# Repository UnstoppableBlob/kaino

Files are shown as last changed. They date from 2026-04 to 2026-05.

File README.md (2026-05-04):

# Kaino (or Kiano)

## What this project is

Here's a short story about this project! I wanted a keyboard from Casio, but it was too expensive for me, so I made my own. I just made a keyboard which should theoretically be able to connect to my computer, and use LMMS that's on my computer, to play sounds that sound exactly like a real piano! 

## How I made it

I made the schematic and PCB in Kicad, which is my prefered software for this type of stuff. I used Shapr3D on my Ipad for the model of the case. I also used Shapr3D's "Visualize" feature for the renders that I got. I plan to use Cherry MX mechanical keyswitches, which are what I have on my pcb renders. I have made my own custom keycap in Shapr3D, which is what I plan to print out and use. Not only does it look like a piano, it feels like one, too. I have put a hole in all of the piano keycaps, and made them a hinge. Whenever you press on a key, it will have the same rotational movement as a really key has. Obviously, I'm limited with the materials of the keycaps that I produce, as I don't have access to the premium ceramic keys that the real pianos have. In addition, even if I did have access to them, the mechanical keyswitches that I'm using wouldn't be able to support the weight of them, at least without substantial springing. My banner image for it is AI Generated, just a disclaimer, hope that it doesn't cause any issues.

## Schematic

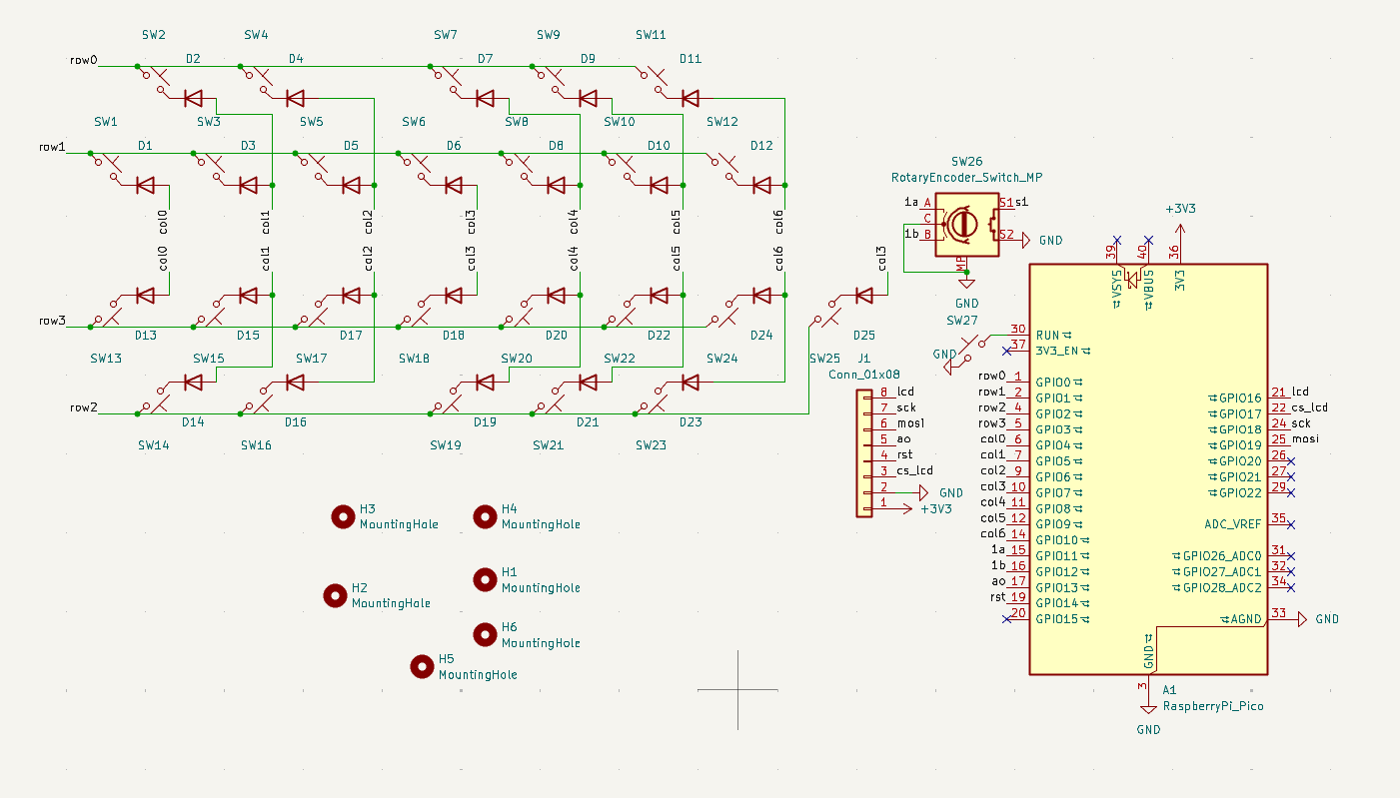
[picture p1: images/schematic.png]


## PCB

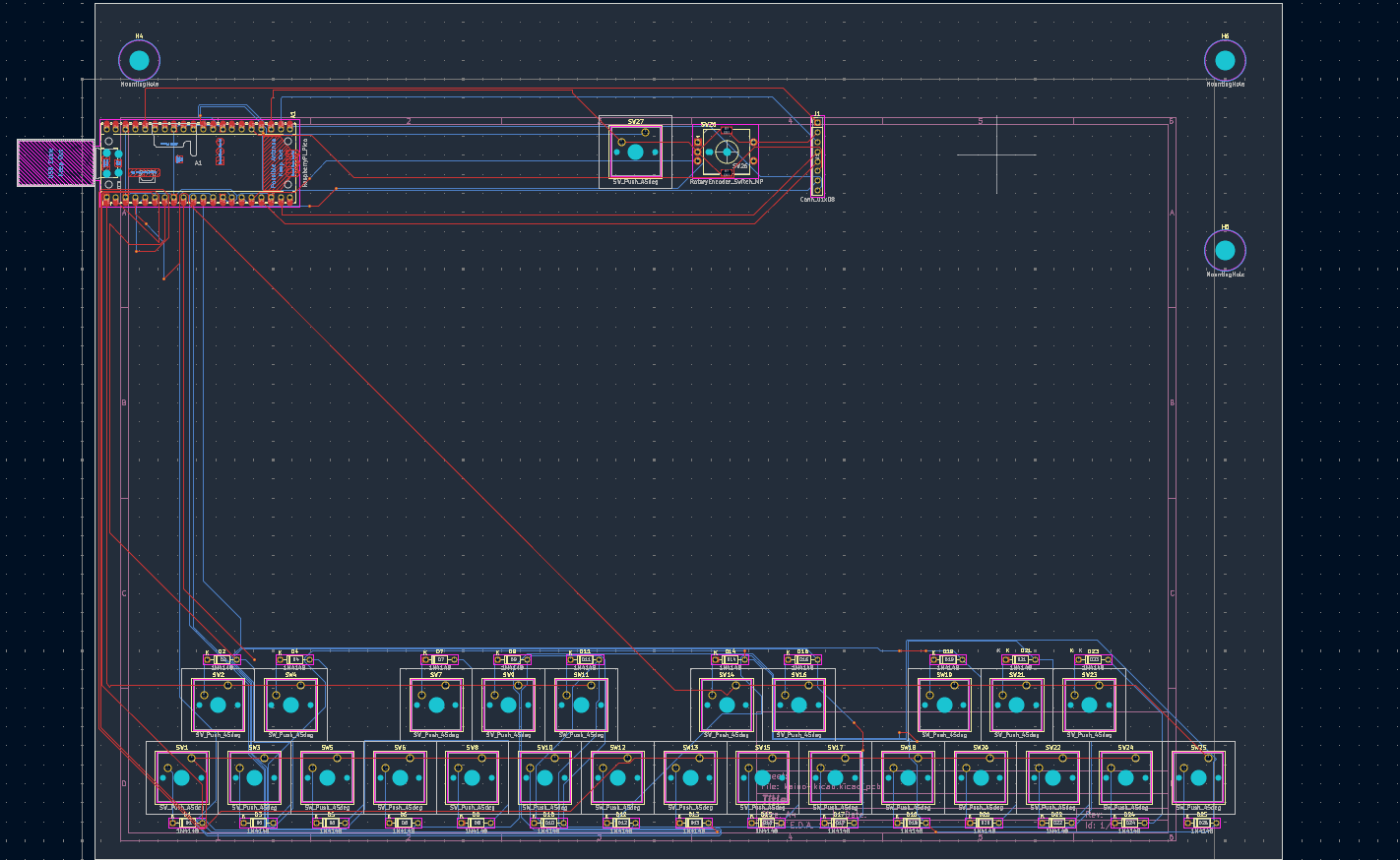
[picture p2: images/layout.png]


## Render #1

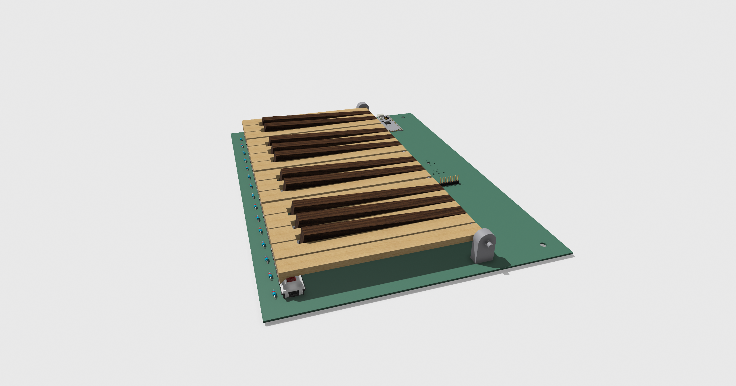
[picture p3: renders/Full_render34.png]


## Render #2

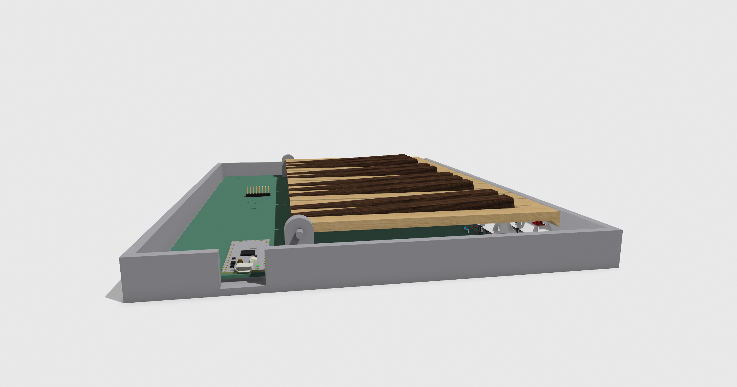
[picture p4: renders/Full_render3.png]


## Render #3

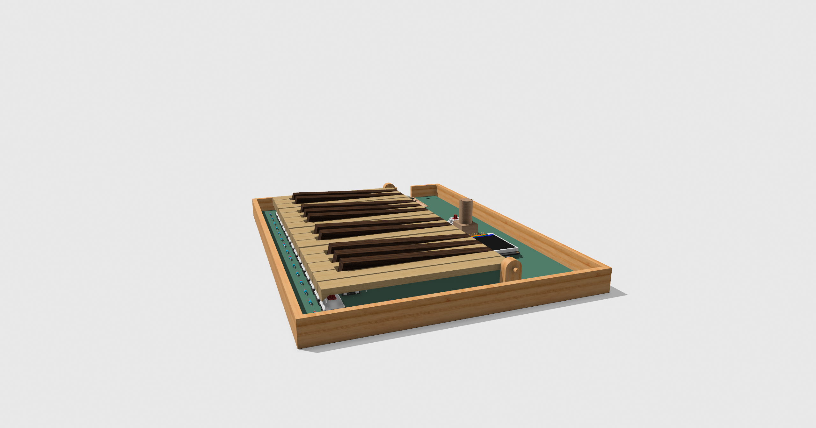
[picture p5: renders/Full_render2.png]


## Render #4

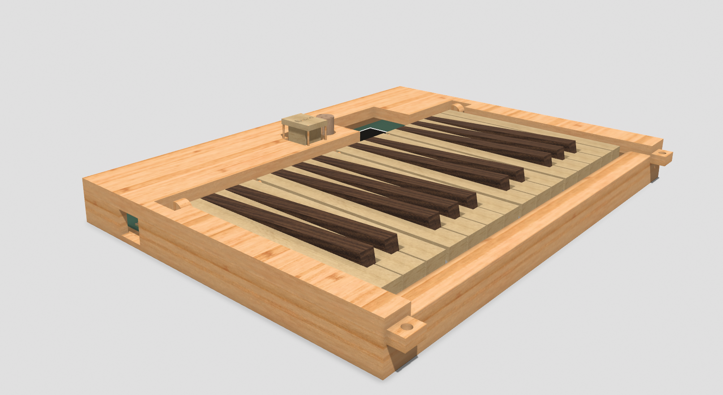
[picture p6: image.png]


## BOM
| Item | Description | Quantity | Unit Price | Total Price | Total (with tax & shipping incl.) | Running Total | Link | | | | | |
|---|---|---|---|---|---|---|---|---|---|---|---|---|
| PCB | PCB from jlcpcb | 5 (jlcpcb minimum) | $0.00 | $0.00 | $0.00 | $0.00 | https://cart.jlcpcb.com/quote | | | | | |
| Cherry MX switches | Cherry MX Switches | 1 | $0.00 | $0.00 | $0.00 | $0.00 | https://www.amazon.com/OUTEMU-Red-Switches-Pin-Switch/dp/B095W1QYPJ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 | | | | | |
| Raspberry Pi pico | MCU | NA | $0.00 | $0.00 | $0.00 | $0.00 | https://www.amazon.com/gp/product/B0C6Q67V97?smid=A1YZW40LYQY3L1&psc=1 | | | | | Since I already have plenty of these in my house, I decided to put $0, but included a link |
| 1N4148W (100pcs) | Diodes | 1 | $0.00 | $0.00 | $0 | $0.00 | https://www.aliexpress.us/item/3256807716771073.html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 | | | | | |
| 3D Prints | 3D printed keys and case | NA | $0 | $0 | My own printer | $0 | NA | | | | | |
| Rotary Encoder (5pcs) | EC11 rotary encoder | 1 | $0.00 | $0.00 | $0 | $0.00 | https://www.amazon.com/gp/product/B0C6Q67V97?smid=A1YZW40LYQY3L1&psc=1 | | | | | I already have some of these lying around from hackpad a long time ago |
| Adafruit 1.8 TFT | LCD Display | 1 | $0.00 | $0.00 | $0.00 | $0.00 | https://www.adafruit.com/product/358 | | | | | |
| | | | | | | Running total is 0 because I'm paying for all costs related to buying parts | | | | | | |

The total amount of money that I would have to spend would be $72.18, since I'm buying parts myself

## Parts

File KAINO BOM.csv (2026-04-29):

Item | Description | Quantity | Unit Price | Total Price | Total (with tax & shipping incl.) | Running Total | Link
PCB | PCB from jlcpcb | 5 (jlcpcb minimum) | $15.43 | $15.43 | $29.84 | $0.00 | https://cart.jlcpcb.com/quote
Kailh Choc v1 (70pcs) | Cherry MX Switches | 1 | $10.99 | $10.99 | $12.36 | $0.00 | https://www.amazon.com/OUTEMU-Red-Switches-Pin-Switch/dp/B095W1QYPJ?sbo=RZvfv%2F%2FHxDF%2BO5021pAnSA%3D%3D
Raspberry Pi pico | MCU | NA | $0.00 | $0.00 | $0.00 | $0.00 | https://www.amazon.com/gp/product/B0C6Q67V97?smid=A1YZW40LYQY3L1&psc=1 | Since I already have plenty of these in my house, I decided to put $0, but included a link
1N4148W (100pcs) | Diodes | 1 | $0.99 | $0.99 | $1 | $0.00 | https://www.aliexpress.us/item/3256807716771073.html?mp=1
3D Prints | 3D printed keys and case | NA | $0 | $0 | My own printer | $0 | NA
Rotary Encoder (5pcs) | EC11 rotary encoder | 1 | $0.00 | $0.00 | $0 | $0.00 | https://www.amazon.com/gp/product/B0C6Q67V97?smid=A1YZW40LYQY3L1&psc=1 | I already have some of these lying around from hackpad a long time ago
 |  |  |  |  |  | Running total is 0 because I'm paying for all costs related to buying parts

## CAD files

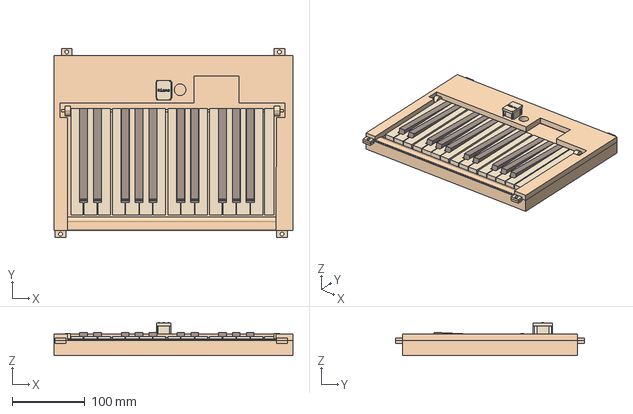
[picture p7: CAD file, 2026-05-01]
CAD/case.step
328.0 x 260.0 x 45.8 mm

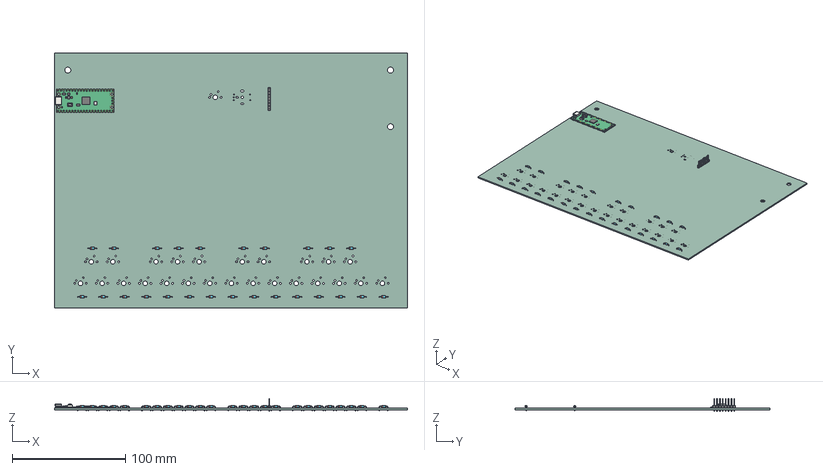
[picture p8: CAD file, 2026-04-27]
kaino-kicad/.step
311.8 x 225.0 x 11.5 mm
D_DO-35_SOD27_P7.62mm_Horizontal x 25
RaspberryPi_Pico_Module_KiCad
PinHeader_1x08_P2.54mm_Vertical
kaino-kicad_PCB

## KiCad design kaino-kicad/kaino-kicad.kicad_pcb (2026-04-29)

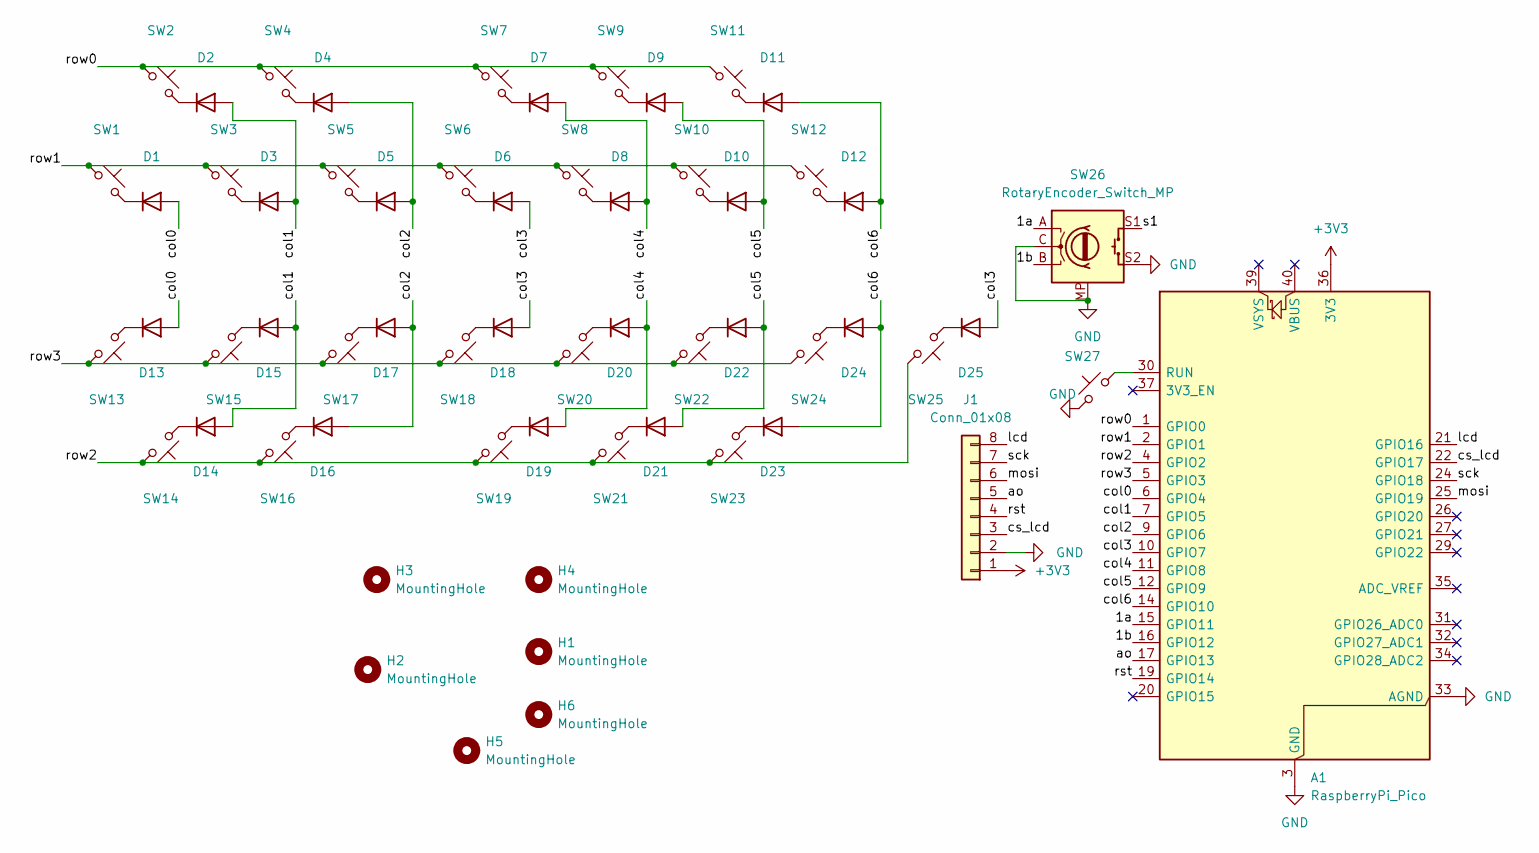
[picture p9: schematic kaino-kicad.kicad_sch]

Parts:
A1: RaspberryPi_Pico; RaspberryPi_Pico_Common_Unspecified
D1, D2, D3, D4, D5, D6, D7, D8, D9, D10, D11, D12, D13, D14, D15, D16, D17, D18, D19, D20, D21, D22, D23, D24, D25: 1N4148; D_DO-35_SOD27_P7.62mm_Horizontal
H1, H2, H3, H4, H5, H6: MountingHole; MountingHole_5.3mm_M5
J1: Conn_01x08; PinHeader_1x08_P2.54mm_Vertical
SW1, SW2, SW3, SW4, SW5, SW6, SW7, SW8, SW9, SW10, SW11, SW12, SW13, SW14, SW15, SW16, SW17, SW18, SW19, SW20, SW21, SW22, SW23, SW24, SW25, SW27: SW_Push_45deg; SW_Cherry_MX_1.00u_PCB
SW26: RotaryEncoder_Switch_MP; RotaryEncoder_Alps_EC11E-Switch_Vertical_H20mm_MountingHoles

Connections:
+3V3: A1.36 (3V3), J1.1
/1a: A1.15 (GPIO11), SW26.A
/1b: A1.16 (GPIO12), SW26.B
/ao: A1.17 (GPIO13), J1.5
/col0: A1.6 (GPIO4), D1.2 (A), D13.2 (A)
/col1: A1.7 (GPIO5), D2.2 (A), D3.2 (A), D14.2 (A), D15.2 (A)
/col2: A1.9 (GPIO6), D4.2 (A), D5.2 (A), D16.2 (A), D17.2 (A)
/col3: A1.10 (GPIO7), D6.2 (A), D18.2 (A), D25.2 (A)
/col4: A1.11 (GPIO8), D7.2 (A), D8.2 (A), D19.2 (A), D20.2 (A)
/col5: A1.12 (GPIO9), D9.2 (A), D10.2 (A), D21.2 (A), D22.2 (A)
/col6: A1.14 (GPIO10), D11.2 (A), D12.2 (A), D23.2 (A), D24.2 (A)
/cs_lcd: A1.22 (GPIO17), J1.3
/lcd: A1.21 (GPIO16), J1.8
/mosi: A1.25 (GPIO19), J1.6
/row0: A1.1 (GPIO0), SW2.1, SW4.1, SW7.1, SW9.1, SW11.1
/row1: A1.2 (GPIO1), SW1.1, SW3.1, SW5.1, SW6.1, SW8.1, SW10.1, SW12.1
/row2: A1.4 (GPIO2), SW14.1, SW16.1, SW19.1, SW21.1, SW23.1, SW25.1
/row3: A1.5 (GPIO3), SW13.1, SW15.1, SW17.1, SW18.1, SW20.1, SW22.1, SW24.1
/rst: A1.19 (GPIO14), J1.4
/s1: SW26.S1
/sck: A1.24 (GPIO18), J1.7
GND: A1.3 (GND), A1.8 (GND), A1.13 (GND), A1.18 (GND), A1.23 (GND), A1.28 (GND), A1.33 (AGND), A1.38 (GND), J1.2, SW26.C, SW26.MP, SW26.S2, SW27.2
unnamed: A1.30 (RUN), SW27.1
unnamed: D1.1 (K), SW1.2
unnamed: D2.1 (K), SW2.2
unnamed: D3.1 (K), SW3.2
unnamed: D4.1 (K), SW4.2
unnamed: D5.1 (K), SW5.2
unnamed: D6.1 (K), SW6.2
unnamed: D7.1 (K), SW7.2
unnamed: D8.1 (K), SW8.2
unnamed: D9.1 (K), SW9.2
unnamed: D10.1 (K), SW10.2
unnamed: D11.1 (K), SW11.2
unnamed: D12.1 (K), SW12.2
unnamed: D13.1 (K), SW13.2
unnamed: D14.1 (K), SW14.2
unnamed: D15.1 (K), SW15.2
unnamed: D16.1 (K), SW16.2
unnamed: D17.1 (K), SW17.2
unnamed: D18.1 (K), SW18.2
unnamed: D19.1 (K), SW19.2
unnamed: D20.1 (K), SW20.2
unnamed: D21.1 (K), SW21.2
unnamed: D22.1 (K), SW22.2
unnamed: D23.1 (K), SW23.2
unnamed: D24.1 (K), SW24.2
unnamed: D25.1 (K), SW25.2

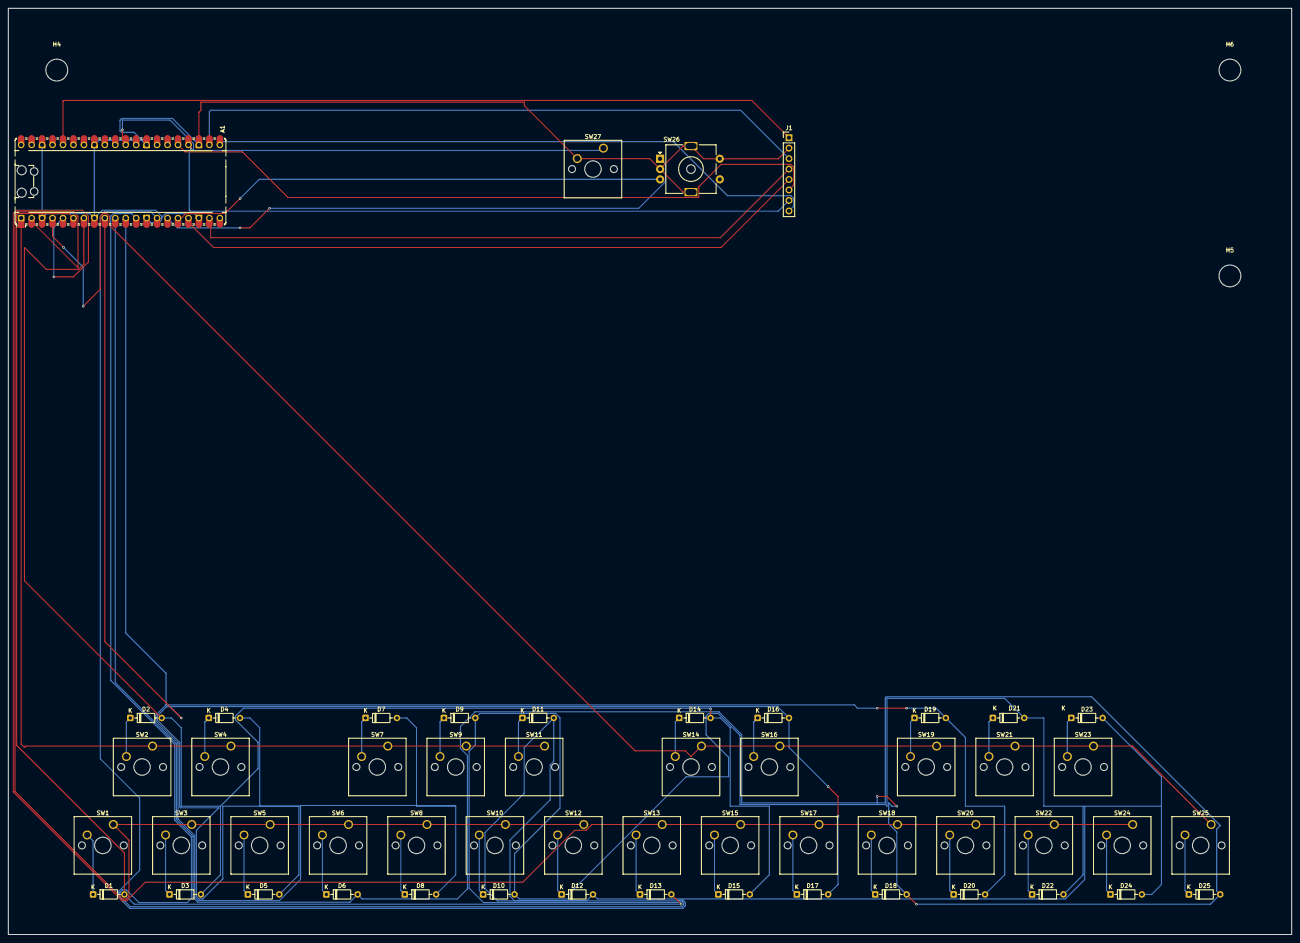
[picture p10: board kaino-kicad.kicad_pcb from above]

Board: 2 copper layers, 311.8 x 225.0 mm, 57 parts (0 on the bottom side), 47 nets.

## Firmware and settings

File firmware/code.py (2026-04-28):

# Encoder short-press = cycle through channels
#Encoder long-press = octave up
# Encoder rotation = volume 

import time
import usb_midi
import adafruit_midi
from adafruit_midi.note_on import NoteOn
from adafruit_midi.note_off import NoteOff
from adafruit_midi.control_change import ControlChange

import config
from matrix import KeyMatrix
from encoder import RotaryEncoder
from display_ui import KeyboardDisplay

print("booting")

midi = adafruit_midi.MIDI(
    midi_out=usb_midi.ports[1],
    out_channel=config.MIDI_CHANNEL,
)

matrix  = KeyMatrix(
    row_gpios  = config.ROW_GPIO,
    col_gpios  = config.COL_GPIO,
    key_map    = config.KEY_MAP,
    debounce_ms= config.DEBOUNCE_MS,
)

enc = RotaryEncoder(
    a_gpio   = config.ENC_A_GPIO,
    b_gpio   = config.ENC_B_GPIO,
    btn_gpio = config.ENC_BTN_GPIO,
    min_val  = 0,
    max_val  = 127,
    initial  = config.DEFAULT_VOLUME,
)

display = KeyboardDisplay(config)


volume        = config.DEFAULT_VOLUME
octave_shift  = 0
midi_channel  = config.MIDI_CHANNEL
active_notes  = set()
OCTAVE_RANGE  = (-3, 3)


midi.send(ControlChange(7, volume))

print("Boot complete — entering main loop")
display.update(active_notes, volume, octave_shift)



def shifted(note):
    return max(0, min(127, note + octave_shift * 12))


def all_notes_off():
    for n in list(active_notes):
        midi.send(NoteOff(n, 0))
    active_notes.clear()


display_dirty = True

while True:

    pressed_raw, released_raw = matrix.scan()

    for raw_note in pressed_raw:
        note = shifted(raw_note)
        if note not in active_notes:
            midi.send(NoteOn(note, volume))
            active_notes.add(note)
            display_dirty = True
            print(f"NoteOn  {note}  vel={volume}")

    for raw_note in released_raw:
        note = shifted(raw_note)
        if note in active_notes:
            midi.send(NoteOff(note, 0))
            active_notes.discard(note)
            display_dirty = True
            print(f"NoteOff {note}")

    vol_delta, short_press, long_press = enc.tick(step=config.VOLUME_STEP)

    if vol_delta != 0:
        volume = enc.value
        midi.send(ControlChange(7, volume))
        display_dirty = True
        print(f"Volume → {volume}")


    if short_press:
        all_notes_off()
        midi_channel = (midi_channel + 1) % 16
        midi = adafruit_midi.MIDI(
            midi_out=usb_midi.ports[1],
            out_channel=midi_channel,
        )
        midi.send(ControlChange(7, volume))
        display_dirty = True
        print(f"MIDI channel → {midi_channel + 1}")


    if long_press:
        all_notes_off()
        lo, hi = OCTAVE_RANGE
        octave_shift = lo if octave_shift >= hi else octave_shift + 1
        display_dirty = True
        print(f"Octave shift → {octave_shift:+d}")


    if display_dirty:
        display.update(active_notes, volume, octave_shift)
        display_dirty = False


    time.sleep(0.001)

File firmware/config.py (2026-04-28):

MIDI_CHANNEL = 0       
DEFAULT_VELOCITY = 100 
DEFAULT_VOLUME = 100 
VOLUME_STEP = 3  
BASE_OCTAVE = 4 


ROW_GPIO = [0, 1, 2, 3]


COL_GPIO = [4, 5, 6, 7, 8, 9, 10]


#   row0 = first-octave  black keys  =  C#4 D#4  –  F#4 G#4 A#4  –
#   row1 = first-octave  white keys  =  C4  D4  E4  F4  G4  A4  B4
#   row2 = second-octave black keys  =  C#5 D#5  –  F#5 G#5 A#5  C6
#   row3 = second-octave white keys  =  C5  D5  E5  F5  G5  A5  B5
#
#         col0  col1  col2  col3  col4  col5  col6
KEY_MAP = [
    [61,   63,   None, 66,   68,   70,   None],
    [60,   62,   64,   65,   67,   69,   71  ],
    [73,   75,   None, 78,   80,   82,   84  ],
    [72,   74,   76,   77,   79,   81,   83  ],
]


ENC_A_GPIO   = 11
ENC_B_GPIO   = 12
ENC_BTN_GPIO = 15



LCD_DC_GPIO   = 13  # GP13 - data
LCD_RST_GPIO  = 14  # GP14 - reset
LCD_BL_GPIO   = 16  # GP16 - backlight
LCD_CS_GPIO   = 17  # GP17 - chip select
LCD_SCK_GPIO  = 18  # GP18 - SPI clock
LCD_MOSI_GPIO = 19  # GP19 - SPI data


LCD_WIDTH     = 128
LCD_HEIGHT    = 160   
LCD_ROTATION  = 0
LCD_BGR       = True 


DEBOUNCE_MS   = 5   

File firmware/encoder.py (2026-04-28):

import rotaryio
import digitalio
import board
import time


class RotaryEncoder:

    def __init__(self, a_gpio, b_gpio, btn_gpio,
                 min_val=0, max_val=127, initial=100,
                 btn_debounce_ms=30, long_press_ms=600):

        self._enc = rotaryio.IncrementalEncoder(
            getattr(board, f"GP{a_gpio}"),
            getattr(board, f"GP{b_gpio}"),
        )
        self._enc.position = 0

        self._btn = digitalio.DigitalInOut(getattr(board, f"GP{btn_gpio}"))
        self._btn.direction = digitalio.Direction.INPUT
        self._btn.pull = digitalio.Pull.UP

        self._min = min_val
        self._max = max_val
        self._value = initial
        self._last_pos = 0

        self._btn_debounce  = btn_debounce_ms / 1000.0
        self._long_press_ms = long_press_ms / 1000.0

        self._btn_raw_last = True
        self._btn_state = True
        self._btn_changed_at = 0.0
        self._btn_pressed_at = 0.0
        self._long_reported = False
        
        
        
    @property
    def value(self):
        return self._value

    @value.setter
    def value(self, v):
        self._value = max(self._min, min(self._max, int(v)))



    def tick(self, step=1):
      
        delta = 0
        short_press = False
        long_press  = False
        now = time.monotonic()

        pos = self._enc.position
        d = pos - self._last_pos
        if d != 0:
            self._last_pos = pos
            new_val = max(self._min, min(self._max, self._value + d * step))
            delta = new_val - self._value
            self._value = new_val


        raw = self._btn.value
        if raw != self._btn_raw_last:
            self._btn_raw_last   = raw
            self._btn_changed_at = now

        if raw != self._btn_state:
            if (now - self._btn_changed_at) >= self._btn_debounce:
                self._btn_state = raw
                if not raw:
                    
                    self._btn_pressed_at = now
                    self._long_reported  = False
                else:
                    
                    held = now - self._btn_pressed_at
                    if held < self._long_press_ms and not self._long_reported:
                        short_press = True


        if (not self._btn_state and not self._long_reported and
                (now - self._btn_pressed_at) >= self._long_press_ms):
            long_press          = True
            self._long_reported = True

        return delta, short_press, long_press

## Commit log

2026-04-27 added from old repo
    [.step, kaino-kicad.kicad_pcb, kaino-kicad.kicad_sch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]
2026-04-27 added CAD assembly
2026-04-29 added bom
    [KAINO BOM.csv]
2026-04-29 fixed bom
    [Kaino BOM - Sheet1.csv, kaino-kicad.kicad_pcb]
2026-04-29 added case
    [case.step]
2026-05-01 added full case
    [case.step]
2026-05-04 update readme and bom
    [Kaino BOM - Sheet1 (4).csv, Kaino BOM - Sheet1.csv]
